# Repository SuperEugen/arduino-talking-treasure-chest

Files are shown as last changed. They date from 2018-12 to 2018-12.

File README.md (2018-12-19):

# talking-treasure-chest
Arduino code that uses an RFID reader, a LED, an audio module, a RTC and a servo.

Treasure Chest

Das ist eine Schatzkiste mit Sprachausgabe, bzw. ein Sprechender Adventskalender. Die Truhe kann ,ot dem richtigen RFID Token geöffnet werden. Durch die eingebaute Uhr mit Kalender kann die Kiste zu unterschiedlichen Tagen und Tageszeiten verschiedene Ansagen machen.

Zuerst wurde ein Endlicher Automat modelliert, der dann im Arduino Code umgesetzt wurde.

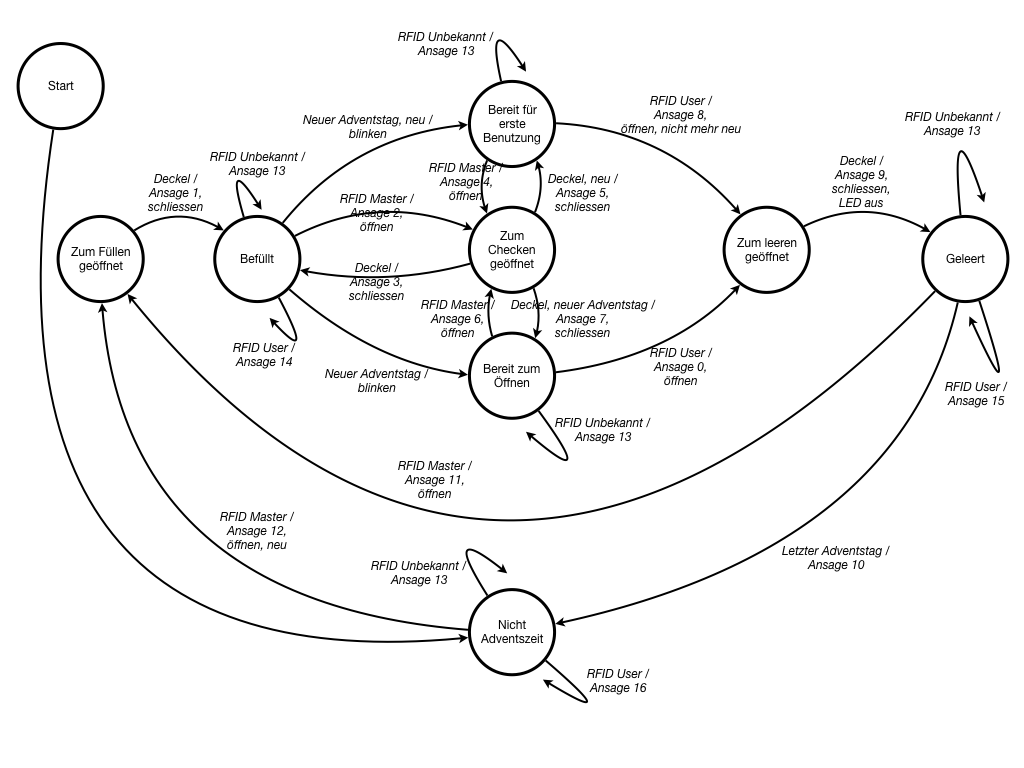
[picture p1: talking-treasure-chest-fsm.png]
Finite State Machine


Die Verkabelung wurde mit Fritzing gezeichnet.

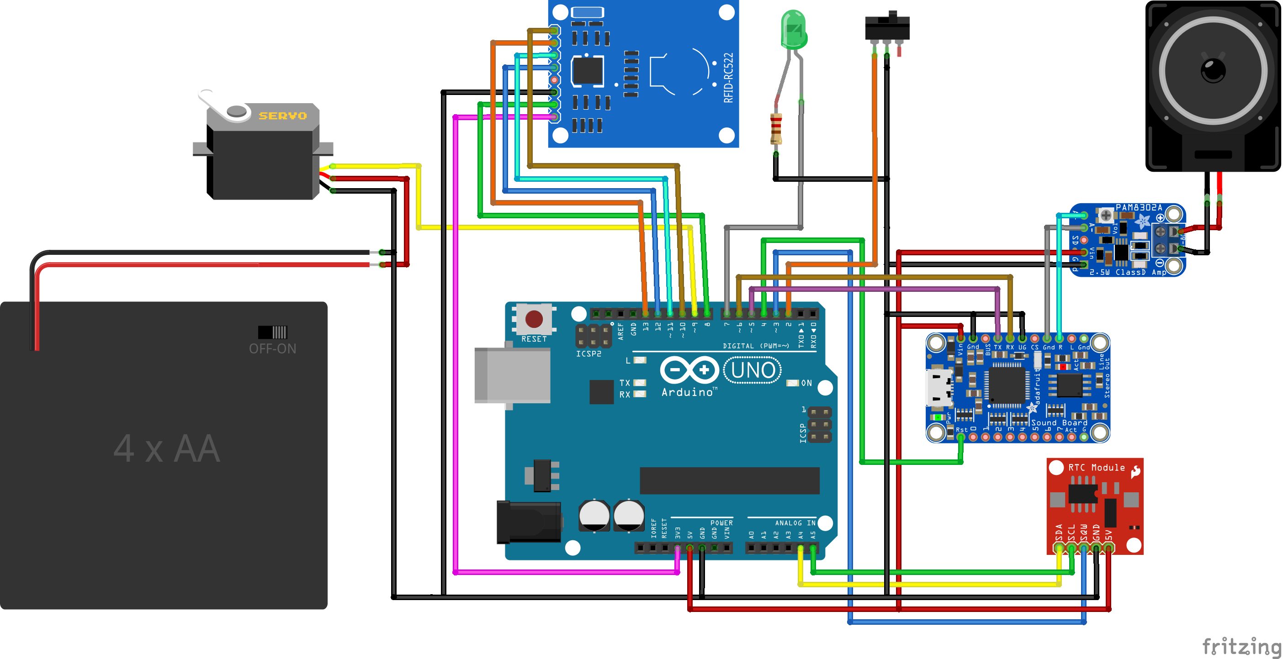
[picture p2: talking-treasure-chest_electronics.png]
Wiring


Das Fusion360 Modell gibt es hier: https://a360.co/2QBVHye

Kurzes Video auf YouTube hier: https://youtu.be/FtdsV8D-JqU

Detailliertere Beschreibung auf meiner Website: https://ingohoffmann.de/bastelprojekt-sprechender-adventskalender/

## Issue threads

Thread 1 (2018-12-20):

doDailyAnnouncement without delay()

SuperEugen, 2018-12-20:
Function doDailyAnnouncement() should avoid using delay() and use remaining track length as described here https://forums.adafruit.com/viewtopic.php?f=19&t=115574

Closed 2025-04-01.

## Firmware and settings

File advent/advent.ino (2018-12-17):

/*
 * advent calendar
 * 
 * Controls a wooden box that acts as a treasure chest used during christmas time. 
 * Every day the box can be opened once by someone with the right RFID token. The box
 * can be opened by another person (santa) with another RFID token to refill the box.
 * After refilled the box indicates that it contains another surprise with a blinking LED.
 * The LED is only blinking from midnight till box is opened and the surprise is taken.
 * The box knows the date and time of day due to its real time clock.
 * A built-in speaker plays severall audio files to greet the person and announce
 * the date.
 * The box has a servo controled lock and the lid has a built-in switch to sense that the
 * box can be locked again.
 * 
 * created by Ingo Hoffmann,    14. November 2018,  initial tests
 * updated by Ingo Hoffmann,    30. November 2018,  finite state machine
 * updated by Ingo Hoffmann,     1. December 2018,  finishing
 * 
 * Components:
 * LED:               connects to a digital pin and uses additional current limiter resistor
 * button:            connects to a digital pin and uses built-in pull-up resistor
 * servo:             connects to a PWM pin
 * Adafruit AudioFX:  connects via UART
 * Adafruit Amp:      connects to AudioFX board
 * Sparkfun RTC:      connects via I2C
 * RFID reader:       connects via SPI
 * 
 * Libraries:
 * Wire.h - Arduino I2C library
 * SoftwareSerial.h - Arduino serial library
 * SPI.h - Arduino SPI library
 * PWMServo.h - servo library using PWM instead of timer
 * SparkFunDS1307RTC.h - Sparkfun RTC library for DS1307
 * Adafruit_Soundboard.h - Adafruit library for Audio FX Soundboard
 * MFRC522.h - GitHub community RFID library
 * 
 */

#include <Wire.h>
#include <SoftwareSerial.h>
#include <SPI.h>
#include <PWMServo.h>
#include <SparkFunDS1307RTC.h>
#include <Adafruit_Soundboard.h>
#include <MFRC522.h>

// Pin connections
#define INFO_LED    7
#define LID_BUTTON  2       // normally open (NO)
//      LID_C       GND     // common (C)
#define LOCK_SERVO  9
#define RFID_SDA    10
#define RFID_SCK    13
#define RFID_MOSI   11
#define RFID_MISO   12
#define RFID_RST    8
#define SFX_TX      5
#define SFX_RX      6
#define SFX_RST     4
//      SFX_UG      GND     // to boot into UART mode
//      RTC_SDA     A4      // I2C
//      RTC_SCL     A5      // I2C
#define RTC_SQW     3
//      AMP_IN+     SFX_GND
//      AMP_IN-     SFX_R

// servo angle
const int LockOpenPos = 120;
const int LockClosedPos = 60;
// debounce of switch
const unsigned long debounceMillis = 20;
// RFID keys
const byte RFIDMasterKey[] = {0x04, 0xFE, 0xB3, 0x7A, 0xAF, 0x48, 0x80};
const byte RFIDStandardKey[] = {0x04, 0x72, 0xD9, 0x7A, 0xAF, 0x48, 0x80};
const byte UserMaster = 1;
const byte UserStandard = 2;
const byte UserUnknown = 3;
// track numbers of AudioFX tracks
const byte AnnouncementBoxFilled = 0;                                     // box closed after opened by master
const byte AnnouncementBoxOpenedForCheck = 1;                             // box opened by master after it was already filled
const byte AnnouncementBoxClosedAfterCheck = 2;                           // box closed after opened by master for check
const byte AnnouncementBoxOpenedForCheckAlreadyPreparedForFirstUse = 3;   // box opened by master but ready for first use
const byte AnnouncementBoxClosedAfterCheckAlreadyPreparedForFirstUse = 4; // box closed after opened by master and ready for first use
const byte AnnouncementBoxOpenedForCheckAlreadyPrepared = 5;              // box opened by master but is already prepared for use
const byte AnnouncementBoxClosedAfterCheckAlreadyPrepared = 6;            // box closed after opened by master and already prepared for use
const byte AnnouncementFirsUseExplanation = 7;                            // box opened by user for the first time
const byte AnnouncementBoxClosed = 8;                                     // box closed by user
const byte AnnouncementLastDay = 9;                                       // box emptied by user on the 24th December
const byte AnnouncementBoxOpenedForFilling = 10;                          // box opened by master
const byte AnnouncementBoxOpenedForFirstFilling = 11;                     // box opened by master after new start
const byte AnnouncementUnknownKey = 12;                                   // unknown RFID key recognized (used in 4 different states)
const byte AnnouncementUserTriedEarly = 13;                               // user tried to open box after it was filled but before next day
const byte AnnouncementUserTriedAgain = 14;                               // user tried to open box after it was emptied and before it was filled again
const byte AnnouncementUserTriedOffSeason = 15;                           // user tried before 1st December or after last opening on 24th or later
const byte DaylyEarlyMorningGreeting = 16;                                // greeting after user opened box between 5:00am and 7:00am
const byte DaylyMorningGreeting = 17;                                     // greeting after user opened box between 7:0am and 11:00am
const byte DaylyGreeting = 18;                                            // greeting after user opened box all other times
const byte DaylyAnnouncement[] = {19, 20, 21, 22, 23, 24, 25, 26,         // list of track numbers for the dayly announcements
                                  27, 28, 29, 30, 31, 32, 33, 34,         // subtract 1 from the current because the array is zero based
                                  35, 36, 37, 38, 39, 40, 41, 42};
// states of the finite state machine
const byte StateOpenedForFilling = 1;
const byte StateFilled = 2;
const byte StateReadyForFirstUse = 3;
const byte StateOpenedForChecking = 4;
const byte StateReadyForUse = 5;
const byte StateOpenedForEmptiing = 6;
const byte StateEmpty = 7;
const byte StateOffSeason = 8;

// global variables
int8_t lastMinute = -1;
int8_t lastDay = -1;
int8_t lastState = -1;
volatile unsigned long lastMillis = 0;
byte userKey = UserUnknown;
byte boxState = StateOffSeason;
bool blinking = false;
bool firstUse = true;

// global object variables
PWMServo lockServo;
SoftwareSerial softSerial = SoftwareSerial(SFX_TX, SFX_RX);
Adafruit_Soundboard sfx = Adafruit_Soundboard(&softSerial, NULL, SFX_RST);
MFRC522 rfid(RFID_SDA, RFID_RST);

void setup() {
  Serial.begin(115200);
  softSerial.begin(9600);
  SPI.begin();

  // info LED
  pinMode(INFO_LED, OUTPUT);

  // lid button
  pinMode(LID_BUTTON, INPUT_PULLUP);

  // real time clock
  pinMode(RTC_SQW, INPUT_PULLUP);
  rtc.begin();
  rtc.writeSQW(SQW_SQUARE_1);
  // set time manually, seconds, minutes, hours, day of week (1=sunday), day, month, year (2 digits)
//  rtc.setTime(10, 55, 11, 1, 18, 11, 18); // comment out once the RTC is set!!!

  // sound board
  sfx.reset();

  // RFID reader
  rfid.PCD_Init();

  // servo
  lockServo.attach(LOCK_SERVO);
  lockServo.write(LockClosedPos);
  delay(15);
  lockServo.detach();

  // state machine start
  boxState = StateOffSeason;
}

void loop() {
  // print date and time every minute
  rtc.update();
  if(rtc.minute() != lastMinute) {  // if the minute has changed
    printTime();                    // print the new time
    lastMinute = rtc.minute();      // update lastMinute value
  }
  
  // blink info LED
  if(blinking) {
    digitalWrite(INFO_LED, digitalRead(RTC_SQW));
  } else {
    digitalWrite(INFO_LED, LOW);
  }

  // finite state machine
  switch(boxState) {
    case StateOpenedForFilling:
      if(lastState != boxState) {
        Serial.println("State: Openend for filling");
        lastState = boxState;
      }
      // lid closed?
      if(digitalRead(LID_BUTTON) == LOW) {
        playTrack(AnnouncementBoxFilled);
        lockLid();
        boxState = StateFilled;
      }
      break;
    case StateFilled:
      if(lastState != boxState) {
        Serial.println("State: Filled");
        lastState = boxState;
      }
      // december and new day and first use?
      if((rtc.month() == 12) && (rtc.date() != lastDay) && firstUse) {
        lastDay = rtc.date();
        blinking = true;
        boxState = StateReadyForFirstUse;
        break;
      }
      // december and new day?
      if((rtc.month() == 12) && (rtc.date() != lastDay)) {
        blinking = true;
        boxState = StateReadyForUse;
        break;
      }
      if(rfid.PICC_IsNewCardPresent()) {
        if(rfid.PICC_ReadCardSerial()) {
          userKey = readRFIDKey();
          switch(userKey) {
            case UserMaster:
              // RFID master?
              playTrack(AnnouncementBoxOpenedForCheck);
              unlockLid();
              delay(5000);
              boxState = StateOpenedForChecking;
              break;
            case UserStandard:
              // RFID user?
              playTrack(AnnouncementUserTriedEarly);
              boxState = StateFilled;
              break;
           case UserUnknown:
              // RFID unknown?
              playTrack(AnnouncementUnknownKey);
              boxState = StateFilled;
              break;  
          }
        }
      }
      break;
    case StateReadyForFirstUse:
      if(lastState != boxState) {
        Serial.println("State: Ready for first use");
        lastState = boxState;
      }
      if(rfid.PICC_IsNewCardPresent()) {
        if(rfid.PICC_ReadCardSerial()) {
          userKey = readRFIDKey();
          switch(userKey) {
            case UserMaster:
              // RFID master?
              playTrack(AnnouncementBoxOpenedForCheckAlreadyPreparedForFirstUse);
              unlockLid();
              delay(5000);
              boxState = StateOpenedForChecking;
              break;
            case UserStandard:
              // RFID user?
              playTrack(AnnouncementFirsUseExplanation);
              delay(30000);
              firstUse = false;
              lastDay = rtc.date();
              unlockLid();
              delay(5000);
              boxState = StateOpenedForEmptiing;
              break;
           case UserUnknown:
              // RFID unknown?
              playTrack(AnnouncementUnknownKey);
              boxState = StateReadyForFirstUse;
              break;  
          }
        }
      }
      break;
    case StateOpenedForChecking:
      if(lastState != boxState) {
        Serial.println("State: Openend for checking");
        lastState = boxState;
      }
      // lid closed and first use?
      if((digitalRead(LID_BUTTON) == LOW) && firstUse) {
        playTrack(AnnouncementBoxClosedAfterCheckAlreadyPreparedForFirstUse);
        lockLid();
        boxState = StateReadyForFirstUse;
        break;
      }
      // lid closed and new day?
      if((digitalRead(LID_BUTTON) == LOW) && (rtc.date() != lastDay)) {
        playTrack(AnnouncementBoxClosedAfterCheckAlreadyPrepared);
        lockLid();
        boxState = StateReadyForUse;
        break;
      }
      // lid closed?
      if(digitalRead(LID_BUTTON) == LOW) {
        playTrack(AnnouncementBoxClosedAfterCheck);
        lockLid();
        boxState = StateFilled;
        break;
      }
    case StateReadyForUse:
      if(lastState != boxState) {
        Serial.println("State: Ready for use");
        lastState = boxState;
      }
      if(rfid.PICC_IsNewCardPresent()) {
        if(rfid.PICC_ReadCardSerial()) {
          userKey = readRFIDKey();
          switch(userKey) {
            case UserMaster:
              // RFID master?
              playTrack(AnnouncementBoxOpenedForCheckAlreadyPrepared);
              unlockLid();
              delay(5000);
              boxState = StateOpenedForChecking;
              break;
            case UserStandard:
              // RFID user?
              doDailyAnnouncement();
              lastDay = rtc.date();
              unlockLid();
              delay(5000);
              boxState = StateOpenedForEmptiing;
              break;
           case UserUnknown:
              // RFID unknown?
              playTrack(AnnouncementUnknownKey);
              boxState = StateReadyForUse;
              break;  
          }
        }
      }
      break;
    case StateOpenedForEmptiing:
      if(lastState != boxState) {
        Serial.println("State: Openend for emptiing");
        lastState = boxState;
      }
      // lid closed?
      if(digitalRead(LID_BUTTON) == LOW) {
        playTrack(AnnouncementBoxClosed);
        lockLid();
        blinking = false;
        boxState = StateEmpty;
      }
      break;
    case StateEmpty:
      if(lastState != boxState) {
        Serial.println("State: Empty");
        lastState = boxState;
      }
      // last day?
      if(rtc.date() == 24) {
        playTrack(AnnouncementLastDay);
        boxState = StateOffSeason;
        break;        
      }
      if(rfid.PICC_IsNewCardPresent()) {
        if(rfid.PICC_ReadCardSerial()) {
          userKey = readRFIDKey();
          switch(userKey) {
            case UserMaster:
              // RFID master?
              playTrack(AnnouncementBoxOpenedForFilling);
              unlockLid();
              delay(5000);
              boxState = StateOpenedForFilling;
              break;
            case UserStandard:
              // RFID user?
              playTrack(AnnouncementUserTriedAgain);
              boxState = StateEmpty;
              break;
           case UserUnknown:
              // RFID unknown?
              playTrack(AnnouncementUnknownKey);
              boxState = StateEmpty;
              break;  
          }
        }
      }
      break;
    case StateOffSeason:
      if(lastState != boxState) {
        Serial.println("State: Off season");
        lastState = boxState;
      }
      if(rfid.PICC_IsNewCardPresent()) {
        if(rfid.PICC_ReadCardSerial()) {
          userKey = readRFIDKey();
          switch(userKey) {
            case UserMaster:
              // RFID master?
              playTrack(AnnouncementBoxOpenedForFirstFilling);
              unlockLid();
              delay(6000);
              if((rtc.month() == 12) && (rtc.date() == 1)) {
                firstUse = true;
                Serial.println("First use");
              } else {
                firstUse = false;
                Serial.println("Skip first use");
              }
              boxState = StateOpenedForFilling;
              break;
            case UserStandard:
              // RFID user?
              playTrack(AnnouncementUserTriedOffSeason);
              boxState = StateOffSeason;
              break;
           case UserUnknown:
              // RFID unknown?
              playTrack(AnnouncementUnknownKey);
              boxState = StateOffSeason;
              break;  
          }
        }
      } 
      break;
  }
}

void doDailyAnnouncement() {
  uint32_t current;
  uint32_t total;
  
  if((rtc.hour() > 5) && (rtc.hour() < 7)) {
    playTrack(DaylyEarlyMorningGreeting);
  } else if((rtc.hour() > 5) && (rtc.hour() < 11)) {
    playTrack(DaylyMorningGreeting);
  } else {
    playTrack(DaylyGreeting);
  }
  delay(5000);
  playTrack(DaylyAnnouncement[rtc.date() - 1]);
}

void playTrack(byte track) {
  if(! sfx.playTrack(track)) {
    Serial.print("Failed to play track ");
    Serial.println(track);
  }   
}

void lockLid() {
  lockServo.attach(LOCK_SERVO);
  lockServo.write(LockClosedPos);
  delay(500);
  lockServo.detach();  
}

void unlockLid() {
  lockServo.attach(LOCK_SERVO);
  lockServo.write(LockOpenPos);
  delay(500);
  lockServo.detach();

}

byte readRFIDKey() {
  if(rfid.uid.size == sizeof(RFIDMasterKey)) {
    if(memcmp(rfid.uid.uidByte, RFIDMasterKey, sizeof(RFIDMasterKey)) == 0) {
      return UserMaster;
    }
  }
  if(rfid.uid.size == sizeof(RFIDStandardKey)) {
    if(memcmp(rfid.uid.uidByte, RFIDStandardKey, sizeof(RFIDStandardKey)) == 0) {
      return UserStandard;
    }
  }
  return UserUnknown;
}

void printTime() {
  switch(rtc.day()) {                           // print weekday
    case 1: Serial.print("Sonntag"); break;
    case 2: Serial.print("Montag"); break;
    case 3: Serial.print("Dienstag"); break;
    case 4: Serial.print("Mittwoch"); break;
    case 5: Serial.print("Donnerstag"); break;
    case 6: Serial.print("Freitag"); break;
    case 7: Serial.print("Samstag"); break;
  }
  Serial.print(", ");
  Serial.print(String(rtc.date()) + ".");       // print day
  if (rtc.month() < 10) {
    Serial.print('0');                          // print leading '0' for month
  }
  Serial.print(String(rtc.month()) + ".");      // print month
  Serial.print("20" + String(rtc.year()));      // print year with leading "20"
  Serial.print(", ");
  Serial.print(String(rtc.hour()) + ":");       // print hour
  if (rtc.minute() < 10) {
    Serial.print('0');                          // print leading '0' for minute
  }
  Serial.print(String(rtc.minute()) + " Uhr");  // print minute
  Serial.println();
}

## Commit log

2018-12-17 Arduino code
    See connection diagramm in Fritzing.
    [talking-treasure-chest.fzz]
2018-12-17 Fritzing file
    Wiring diagramm
    [talking-treasure-chest-electronics.fzz]
